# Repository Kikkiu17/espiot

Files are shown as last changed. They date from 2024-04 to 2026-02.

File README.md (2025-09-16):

# espiot
A small board built to measure current and voltage of an appliance.<br />
This board was used as a testbed for STM32 ADC oversampler, UART and DMA.<br />
To measure current and voltage values, a 12-bit ADC was used, with an oversampling ratio of 256x and an 8-bit shift to obtain efficient data averaging - this provides stable readings, along with a sampling time of 3.5 cycles for current and 79.5 cycles for voltage. DMA was also used to transfer all the ADC readings into memory without performance losses.

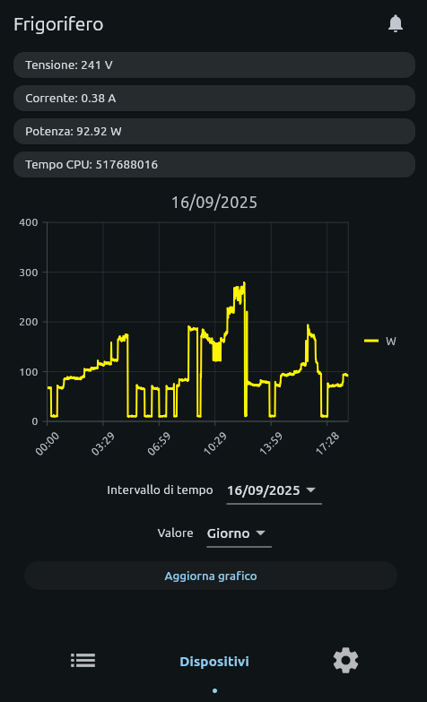
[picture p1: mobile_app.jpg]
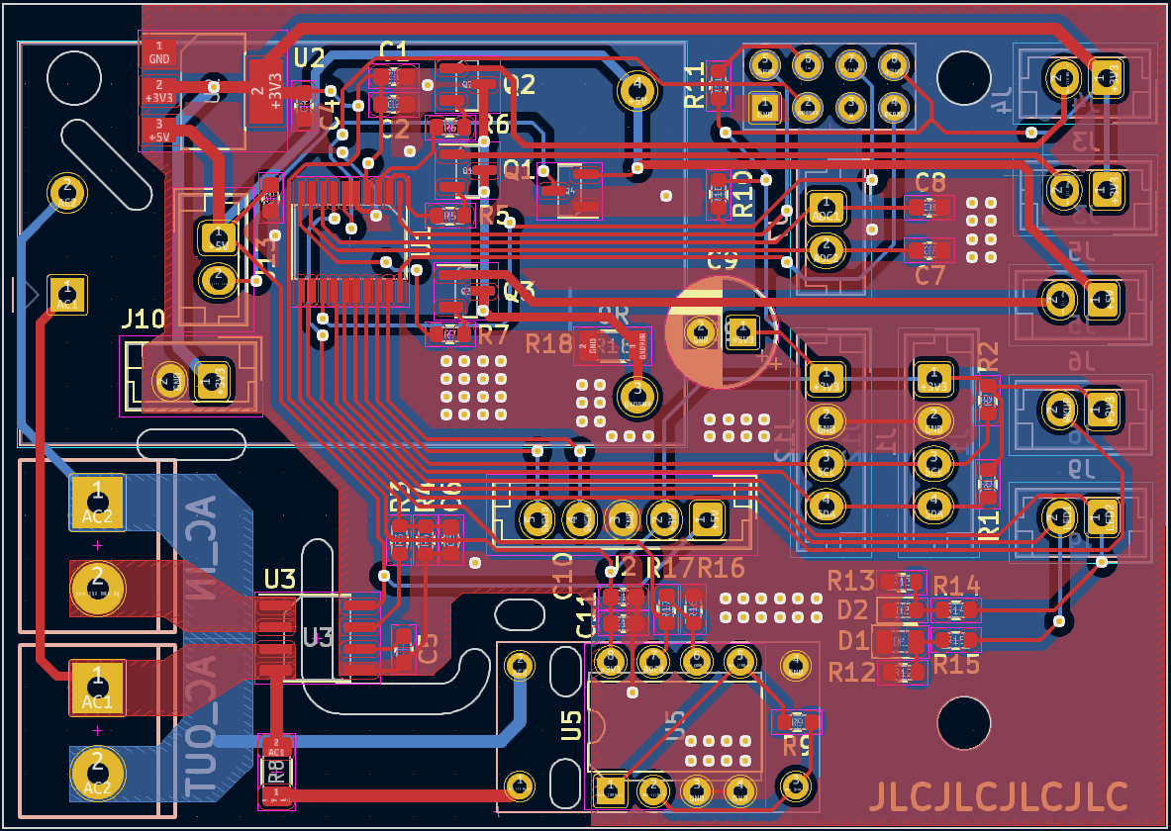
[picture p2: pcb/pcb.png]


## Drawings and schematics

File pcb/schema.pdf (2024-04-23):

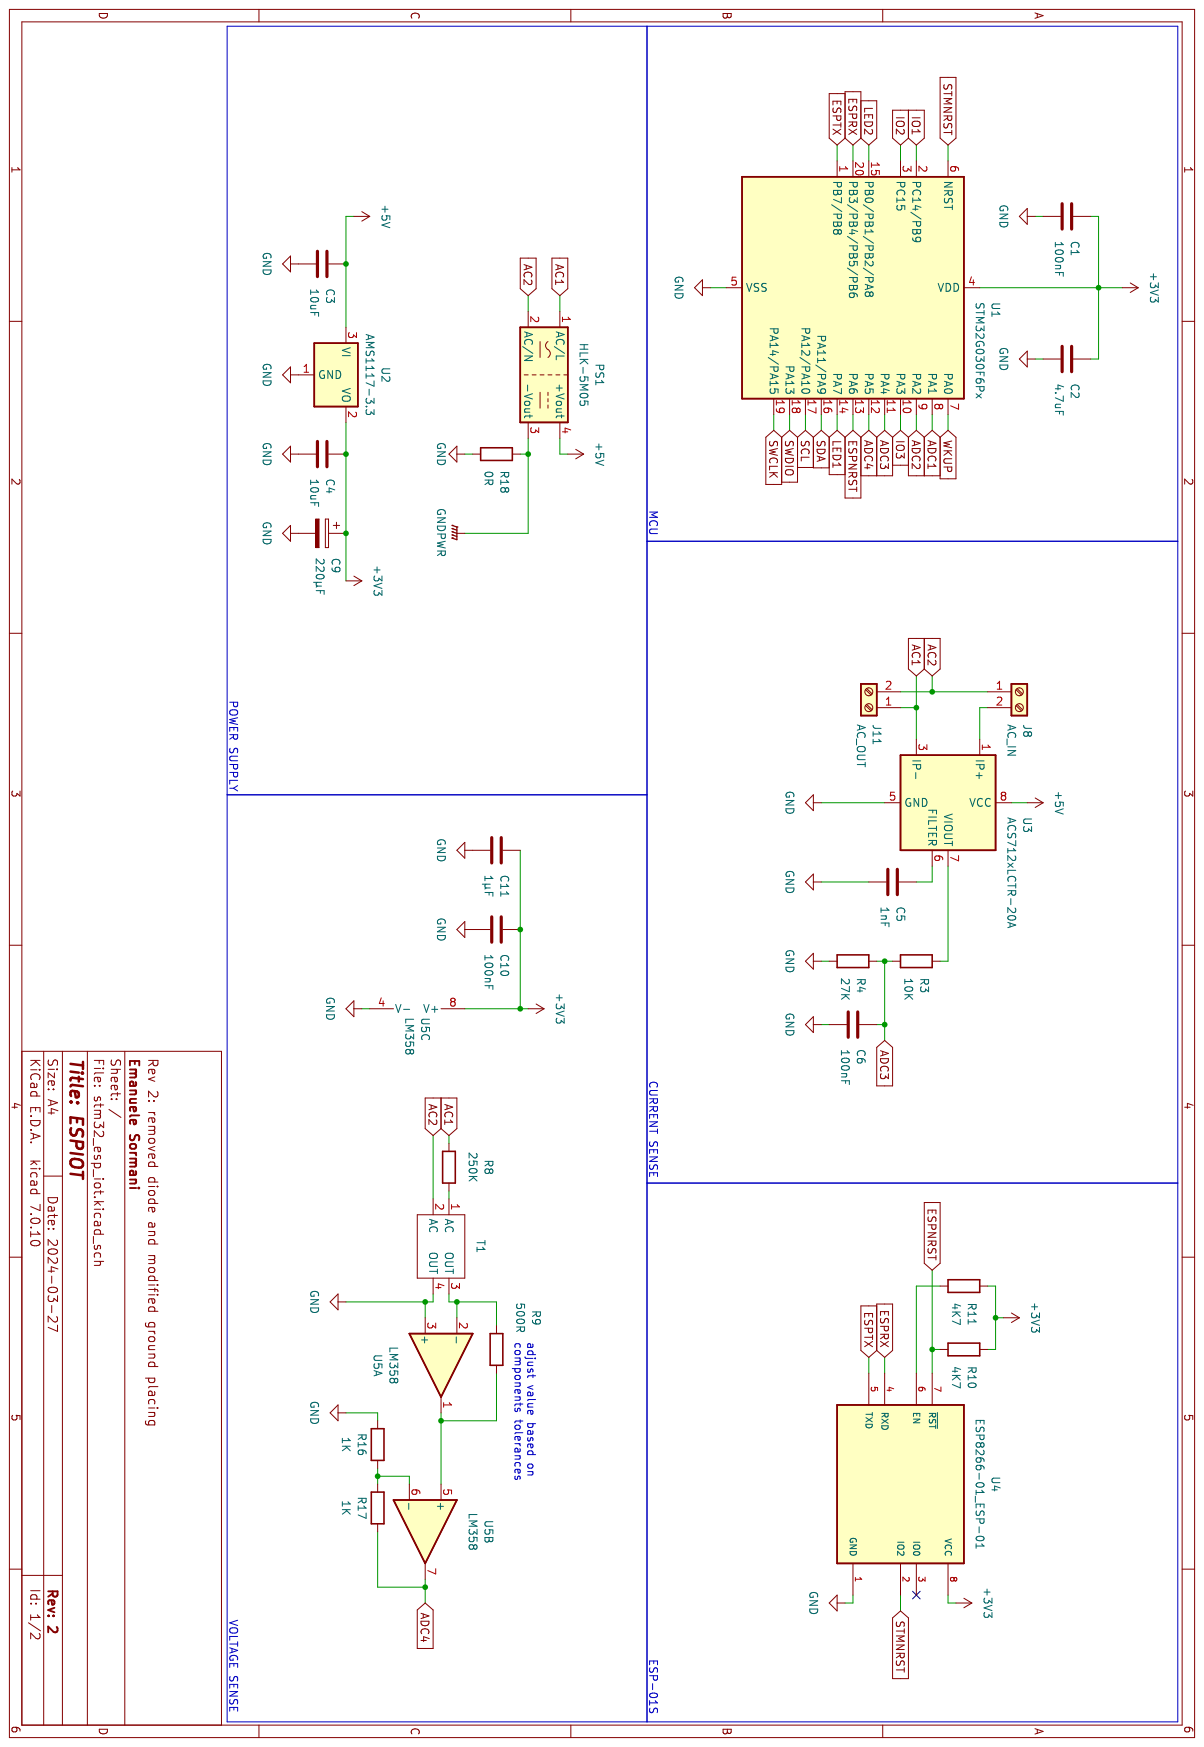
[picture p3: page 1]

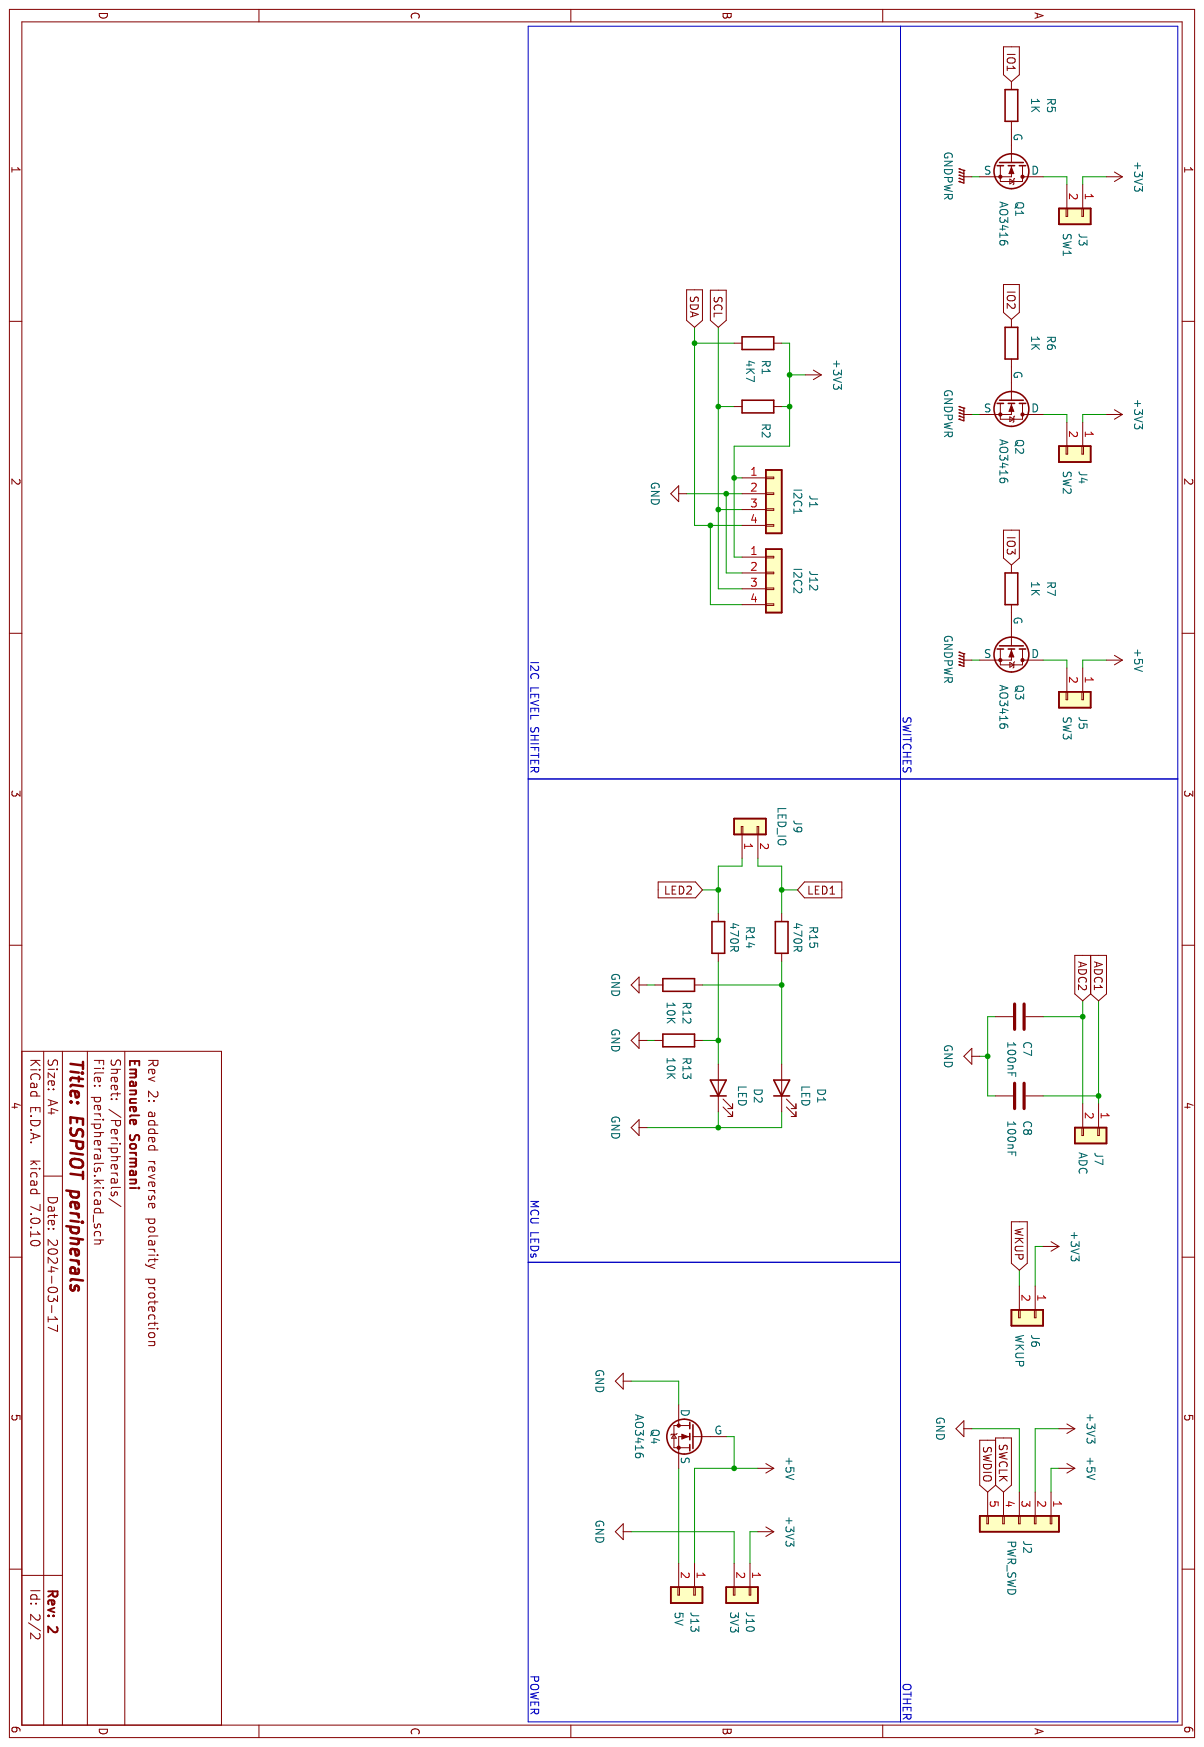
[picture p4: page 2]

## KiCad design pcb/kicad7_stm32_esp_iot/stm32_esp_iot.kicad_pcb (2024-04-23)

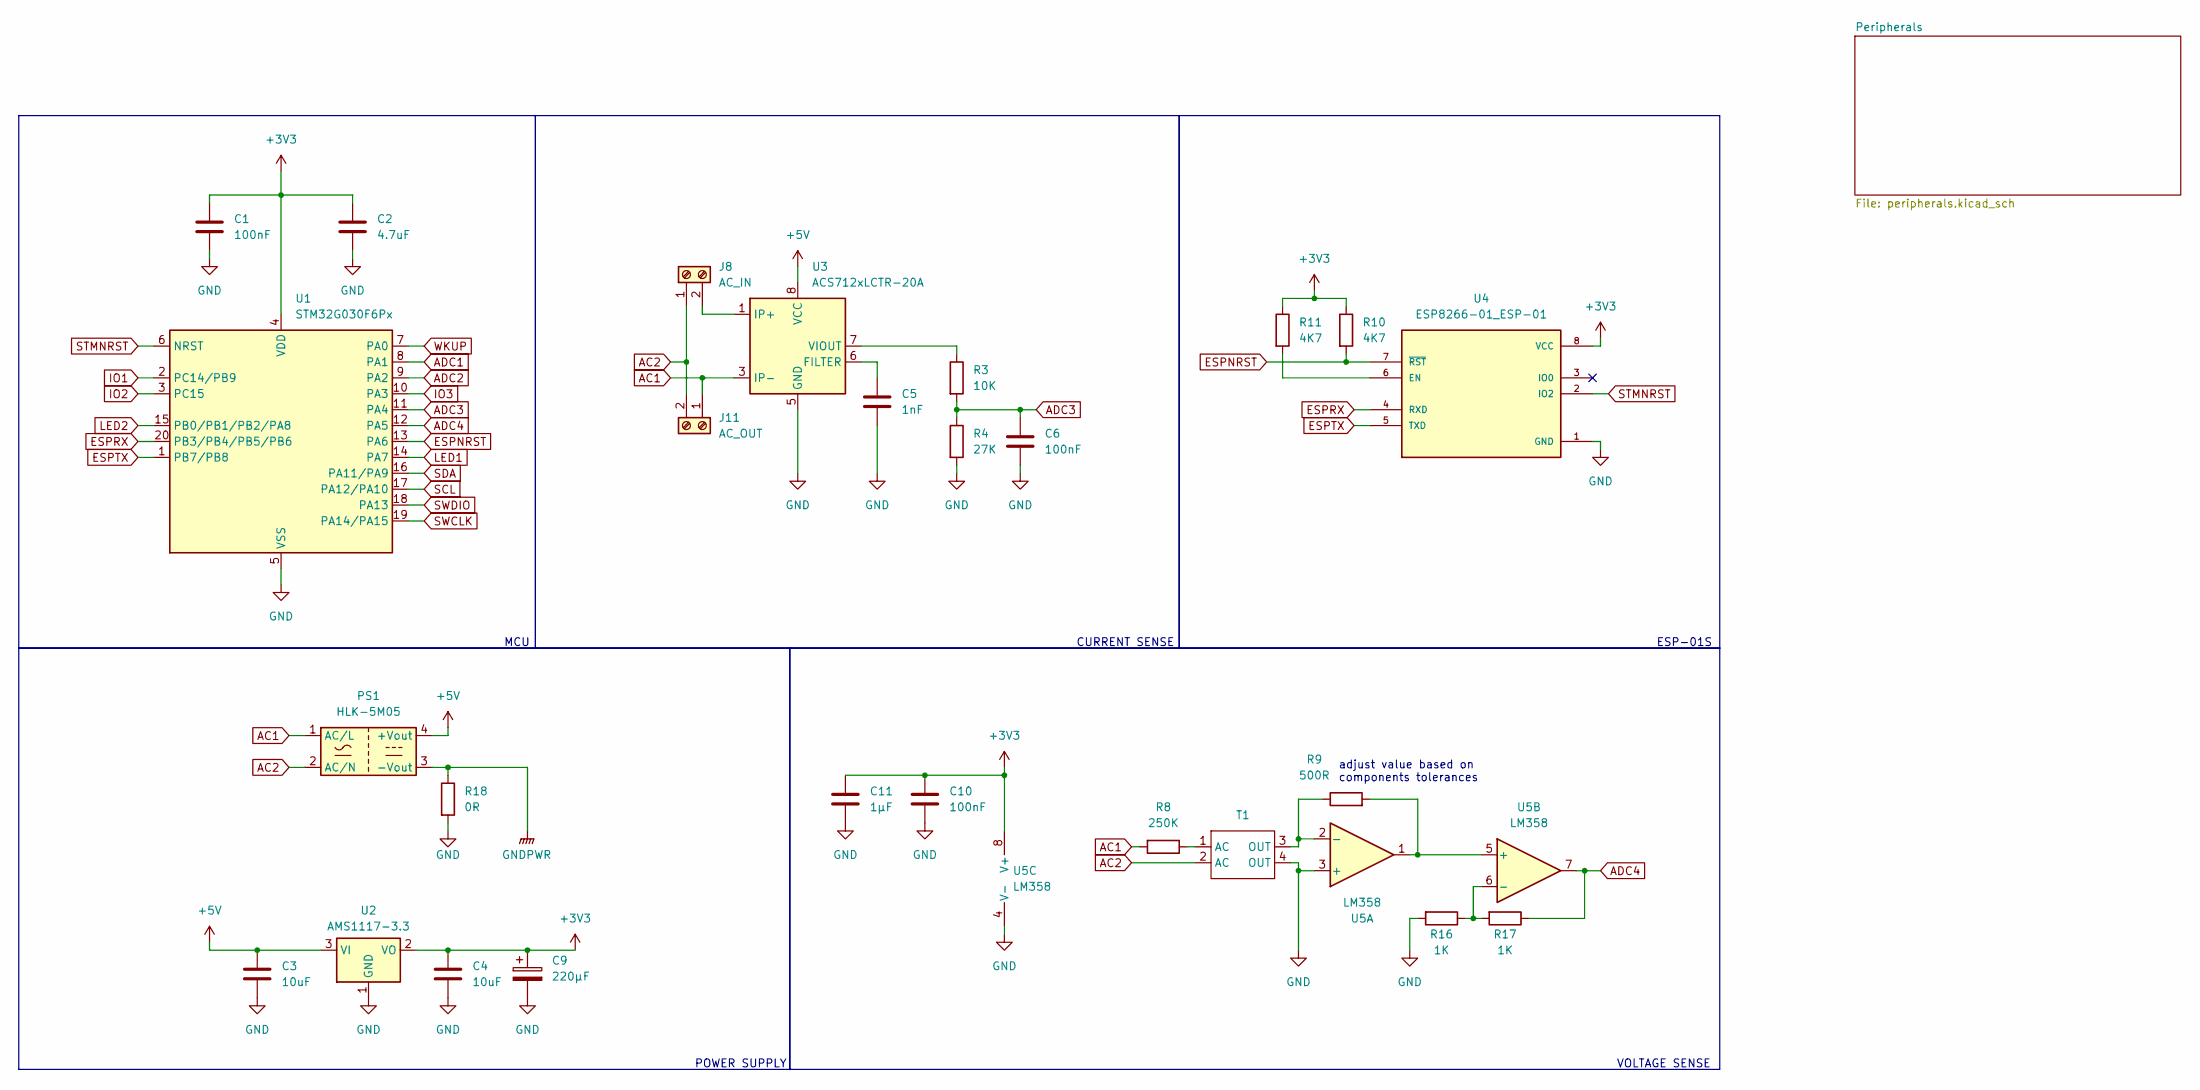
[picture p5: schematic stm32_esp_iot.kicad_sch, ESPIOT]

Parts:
C1, C6, C10: 100nF; C_0603_1608Metric
C2: 4.7uF; C_0603_1608Metric
C3, C4: 10uF; C_0603_1608Metric
C5: 1nF; C_0603_1608Metric
C9: 220µF; CP_Radial_D6.3mm_P2.50mm
C11: 1µF; C_0603_1608Metric
J8: AC_IN; mors_2p
J11: AC_OUT; mors_2p
PS1: HLK-5M05; Converter_ACDC_HiLink_HLK-5Mxx
R3: 10K; R_0603_1608Metric
R4: 27K; R_0603_1608Metric
R8: 250K; R_1206_3216Metric
R9: 500R; R_0603_1608Metric
R10, R11: 4K7; R_0603_1608Metric
R16, R17: 1K; R_0603_1608Metric
R18: 0R; R_1206_3216Metric
T1: ZMPT107
U1: STM32G030F6Px; TSSOP-20_4.4x6.5mm_P0.65mm
U2: AMS1117-3.3; SOT-223-3_TabPin2
U3: ACS712xLCTR-20A; SOIC-8_3.9x4.9mm_P1.27mm
U4: ESP8266-01_ESP-01; esp-01s; PARTREV V1.2
U5: LM358; DIP-8_W7.62mm

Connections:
+3V3: C1.1, C2.1, C4.1, C9.1, C10.1, C11.1, R10.1, R11.1, U1.4 (VDD), U2.2 (VO), U4.8 (VCC), U5.8 (V+); also elsewhere on the board
+5V: C3.1, PS1.4 (+Vout), U2.3 (VI), U3.8 (VCC); also elsewhere on the board
AC1: J11.1, PS1.1 (AC/L), R8.2, U3.3 (IP-), U3.4 (IP-)
AC2: J8.1, J11.2, PS1.2 (AC/N), T1.2 (AC)
ADC1: U1.8 (PA1); also elsewhere on the board
ADC2: U1.9 (PA2); also elsewhere on the board
ADC3: C6.1, R3.2, R4.1, U1.11 (PA4)
ADC4: R17.1, U1.12 (PA5), U5.7
ESPNRST: R10.2, U1.13 (PA6), U4.7 (~RST)
ESPRX: U1.20 (PB3/PB4/PB5/PB6), U4.4 (RXD)
ESPTX: U1.1 (PB7/PB8), U4.5 (TXD)
GND: C1.2, C2.2, C3.2, C4.2, C5.2, C6.2, C9.2, C10.2, C11.2, R4.2, R16.2, R18.2, T1.4 (OUT), U1.5 (VSS), U2.1 (GND), U3.5 (GND), U4.1 (GND), U5.3 (+), U5.4 (V-); also elsewhere on the board
GNDPWR: PS1.3 (-Vout), R18.1; also elsewhere on the board
IO1: U1.2 (PC14/PB9); also elsewhere on the board
IO2: U1.3 (PC15); also elsewhere on the board
IO3: U1.10 (PA3); also elsewhere on the board
LED1: U1.14 (PA7); also elsewhere on the board
LED2: U1.15 (PB0/PB1/PB2/PA8); also elsewhere on the board
unnamed: J8.2, U3.1 (IP+), U3.2 (IP+)
unnamed: R8.1, T1.1 (AC)
unnamed: C5.1, U3.6 (FILTER)
unnamed: R3.1, U3.7 (VIOUT)
unnamed: R11.2, U4.6 (EN)
unnamed: R9.1, T1.3 (OUT), U5.2 (-)
unnamed: R9.2, U5.1, U5.5 (+)
unnamed: R16.1, R17.2, U5.6 (-)
SCL: U1.17 (PA12/PA10); also elsewhere on the board
SDA: U1.16 (PA11/PA9); also elsewhere on the board
STMNRST: U1.6 (NRST), U4.2 (IO2)
SWCLK: U1.19 (PA14/PA15); also elsewhere on the board
SWDIO: U1.18 (PA13); also elsewhere on the board
WKUP: U1.7 (PA0); also elsewhere on the board

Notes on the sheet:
adjust value based on components tolerances
MCU
VOLTAGE SENSE
CURRENT SENSE
ESP-01S
POWER SUPPLY

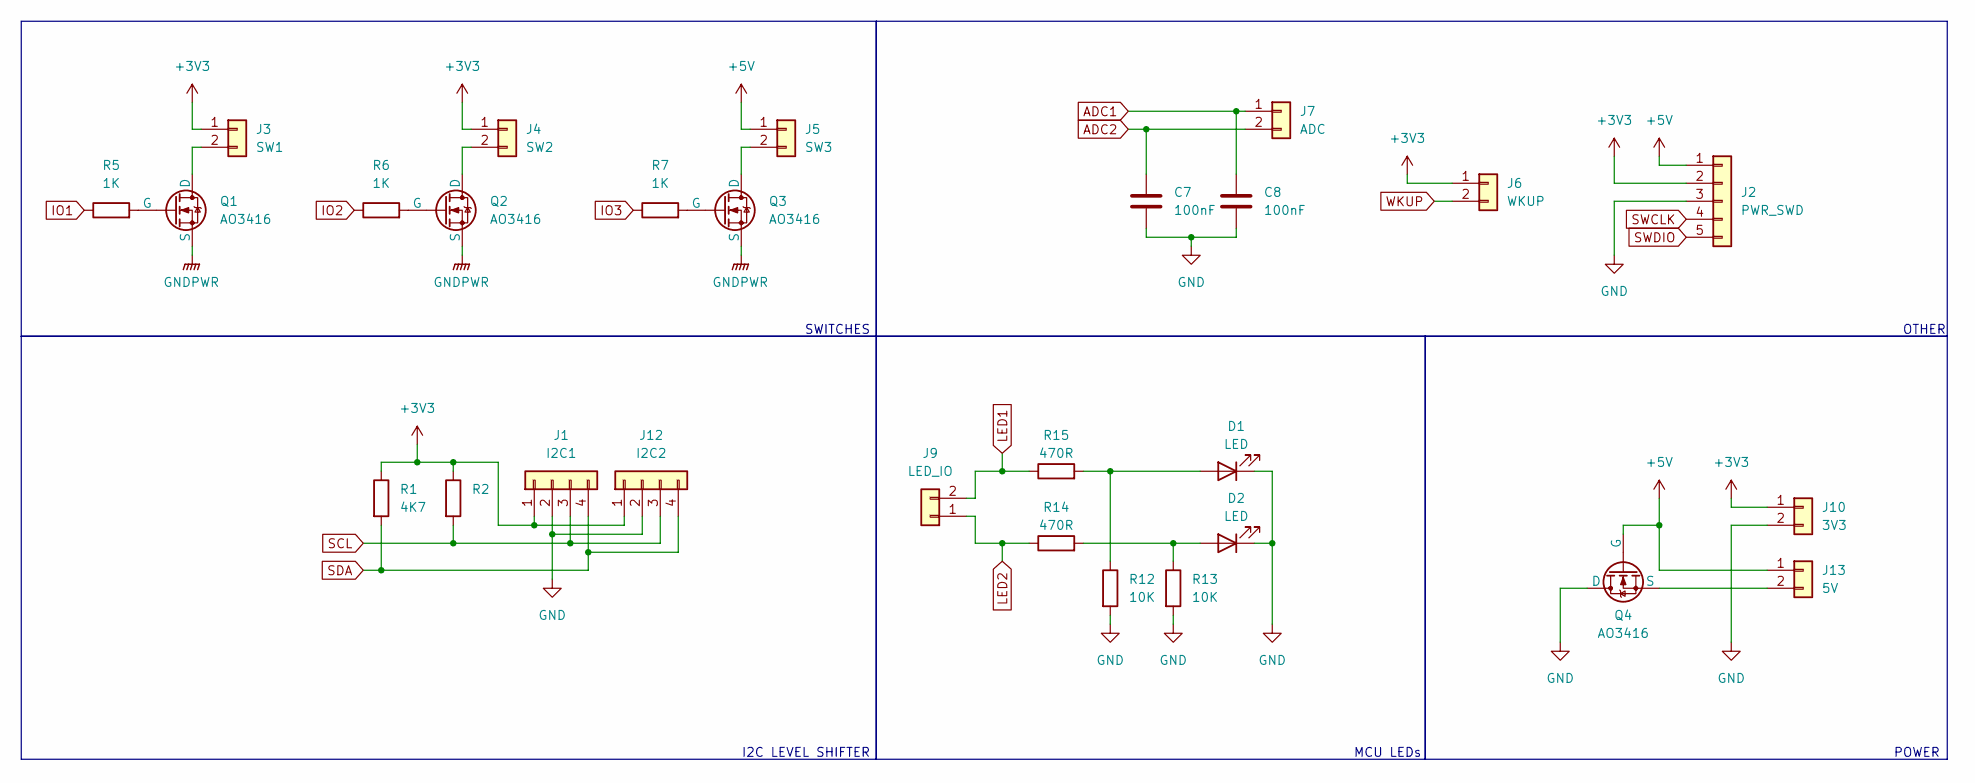
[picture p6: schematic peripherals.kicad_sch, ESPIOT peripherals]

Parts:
C7, C8: 100nF; C_0603_1608Metric
D1: LED; LED_0805_2012Metric
D2: LED; LED_0603_1608Metric
J1: I2C1; JST_EH_B4B-EH-A_1x04_P2.50mm_Vertical
J2: PWR_SWD; JST_EH_B5B-EH-A_1x05_P2.50mm_Vertical
J3: SW1; JST_EH_B2B-EH-A_1x02_P2.50mm_Vertical
J4: SW2; JST_EH_B2B-EH-A_1x02_P2.50mm_Vertical
J5: SW3; JST_EH_B2B-EH-A_1x02_P2.50mm_Vertical
J6: WKUP; JST_EH_B2B-EH-A_1x02_P2.50mm_Vertical
J7: ADC; JST_EH_B2B-EH-A_1x02_P2.50mm_Vertical
J9: LED_IO; JST_EH_B2B-EH-A_1x02_P2.50mm_Vertical
J10: 3V3; JST_EH_B2B-EH-A_1x02_P2.50mm_Vertical
J12: I2C2; JST_EH_B4B-EH-A_1x04_P2.50mm_Vertical
J13: 5V; JST_EH_B2B-EH-A_1x02_P2.50mm_Vertical
Q1, Q2, Q3, Q4: AO3416; SOT-23
R1, R2: 4K7; R_0603_1608Metric
R5, R6, R7: 1K; R_0603_1608Metric
R12, R13: 10K; R_0603_1608Metric
R14, R15: 470R; R_0603_1608Metric

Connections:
+3V3: J1.1, J2.2, J3.1, J4.1, J6.1, J10.1, J12.1, R1.1, R2.1; also elsewhere on the board
+5V: J2.1, J5.1, J13.1, Q4.2 (G); also elsewhere on the board
ADC1: C8.1, J7.1; also elsewhere on the board
ADC2: C7.1, J7.2; also elsewhere on the board
GND: C7.2, C8.2, D1.1 (K), D2.1 (K), J1.2, J2.3, J10.2, J12.2, Q4.1 (D), R12.2, R13.2; also elsewhere on the board
GNDPWR: Q1.3 (S), Q2.3 (S), Q3.3 (S); also elsewhere on the board
IO1: R5.1; also elsewhere on the board
IO2: R6.1; also elsewhere on the board
IO3: R7.1; also elsewhere on the board
LED1: J9.2, R15.1; also elsewhere on the board
LED2: J9.1, R14.1; also elsewhere on the board
unnamed: D1.2 (A), R12.1, R15.2
unnamed: D2.2 (A), R13.1, R14.2
unnamed: J3.2, Q1.1 (D)
unnamed: J4.2, Q2.1 (D)
unnamed: J5.2, Q3.1 (D)
unnamed: J13.2, Q4.3 (S)
unnamed: Q1.2 (G), R5.2
unnamed: Q2.2 (G), R6.2
unnamed: Q3.2 (G), R7.2
SCL: J1.3, J12.3, R2.2; also elsewhere on the board
SDA: J1.4, J12.4, R1.2; also elsewhere on the board
SWCLK: J2.4; also elsewhere on the board
SWDIO: J2.5; also elsewhere on the board
WKUP: J6.2; also elsewhere on the board

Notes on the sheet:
POWER
SWITCHES
MCU LEDs
I2C LEVEL SHIFTER
OTHER

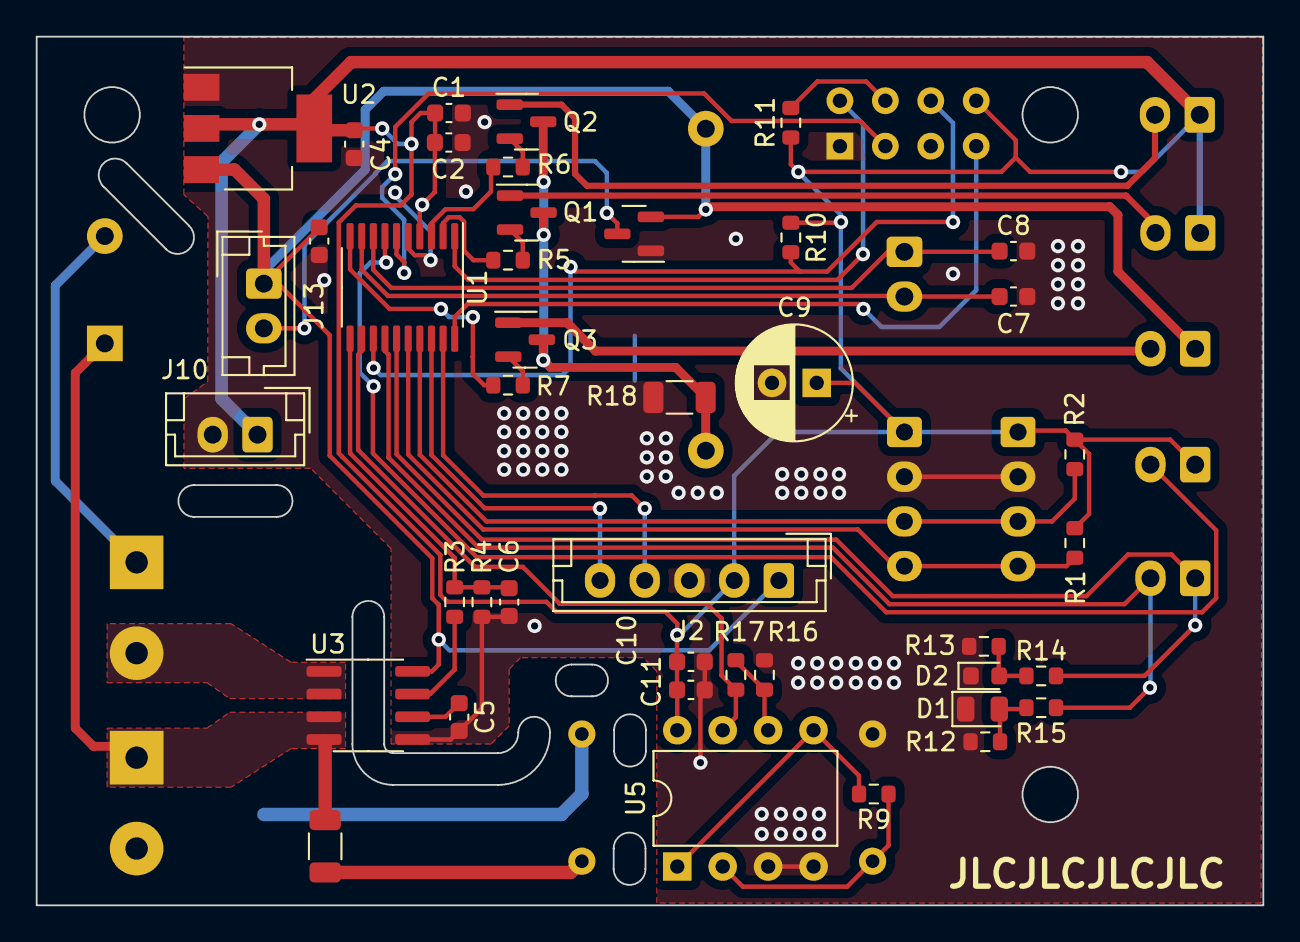
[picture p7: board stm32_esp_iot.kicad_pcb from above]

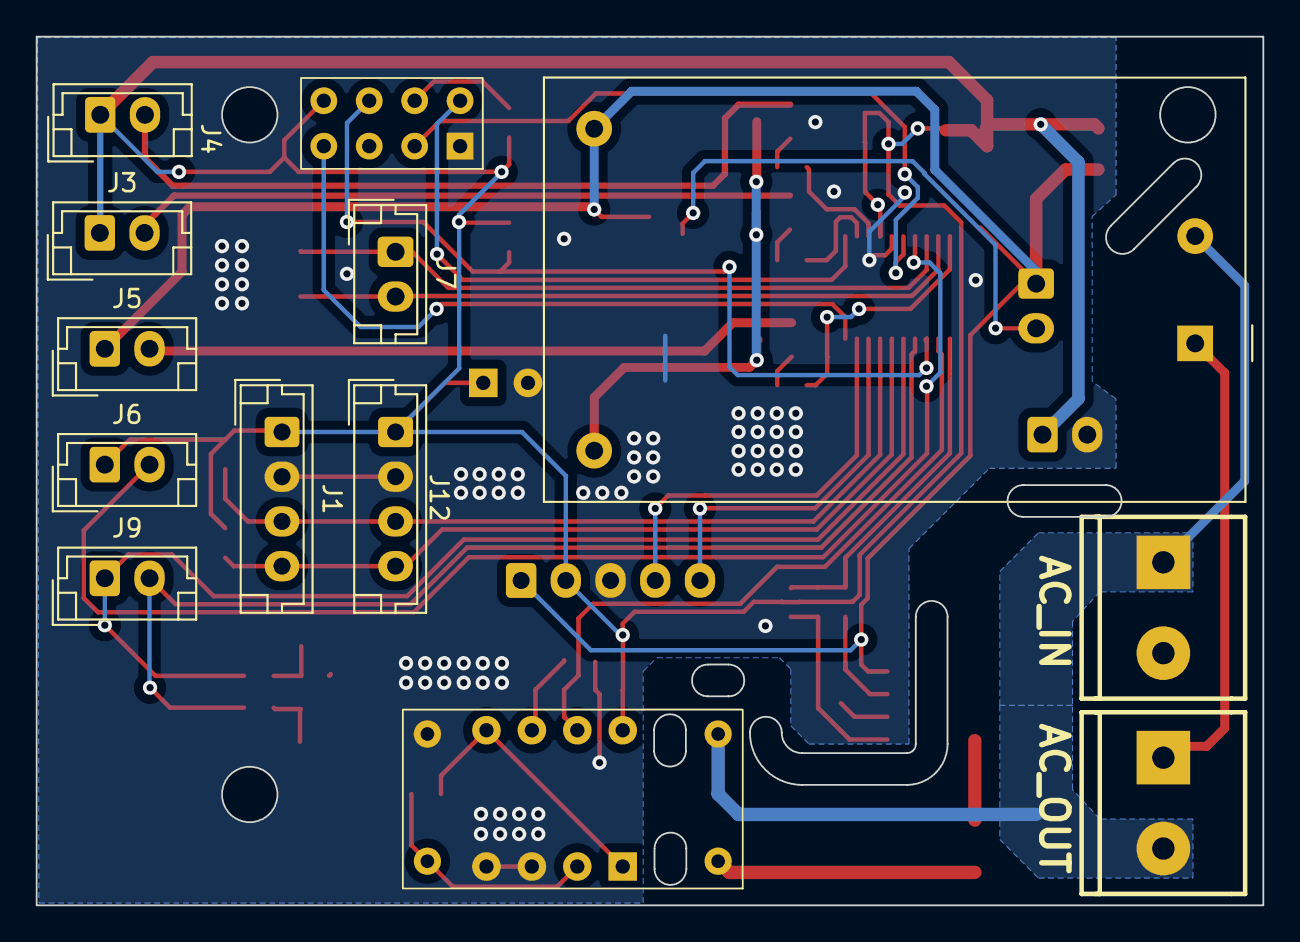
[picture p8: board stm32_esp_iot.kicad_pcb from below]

Board: 2 copper layers, 68.6 x 48.6 mm, 55 parts (13 on the bottom side), 41 nets.

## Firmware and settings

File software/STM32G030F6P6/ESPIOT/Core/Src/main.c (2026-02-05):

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
/* Includes ------------------------------------------------------------------*/
#include "main.h"
#include "adc.h"
#include "dma.h"
#include "tim.h"
#include "usart.h"
#include "gpio.h"

/* USER CODE BEGIN Includes */
#include <string.h>
#include <math.h>
#include <stdio.h>

#include "../credentials.h"
#include "../ESP8266/esp8266.h"
#include "../wifihandler/wifihandler.h"
#include "../Flash/flash.h"
/* USER CODE END Includes */


/* USER CODE BEGIN PV */
uint16_t adc_buf[ADC_BUF_LEN];
uint32_t previous_voltage = 0;

WIFI_t wifi;
Connection_t conn;
/* USER CODE END PV */

void SystemClock_Config(void);
/* USER CODE BEGIN 0 */
float SENS_GetCurrent()
{
	float max = 0, min = 4096;
	// 12-bit ADC must be used
	for (uint32_t i = 0; i < ADC_BUF_LEN; i+=2)
	{
		if (adc_buf[i] > max)
			max = adc_buf[i];
		if (adc_buf[i] < min)
			min = adc_buf[i];
	}

	max = max / 4096.0 * 3.3;
	min = min / 4096.0 * 3.3;

	/*
	 * Irms = measured_amplitude * divider_ratio / 2 / ACS712_sensitivity / √2
	 * where
	 * masured_amplitude = fabsf(max - min)
	 * divider_ratio = 1.37 (voltage divider ratio)
	 * division by two is used to get only one side of the sine wave
	 * ACS712_sensitivity = 0.185 mV/A
	 * division by √2 is used to get RMS value
	 *
	 * the numbers below are obtained by doing these multiplications and division in advance
	 */

	// adjust_value == 1.37 * 1.9145
	float adjust_value = 2.62286;
	float abs_amplitude = fabsf(max - min);
	// used with this particular ACS sensor, since its reading is not linear under 0.6A
	if (abs_amplitude < 0.25)
		adjust_value = 2.09;

	// abs_amplitude * 1.37 * 1.9145
	float Irms = abs_amplitude * adjust_value * CURRENT_CALIB_VALUE;

	if (Irms <= CURRENT_DEAD_ZONE) return 0;
	else return Irms;
}


uint32_t SENS_GetVoltage()
{
	// 12-bit ADC must be used
	uint32_t voltage_mean = 0, voltage = 0;
	for (uint32_t i = 1; i < ADC_BUF_LEN; i+=2)
		voltage_mean += adc_buf[i];

	/*
	 * 0.001745 = 3.3 / (4096 * 1024) * 2255
	 * 2255 is a calibration value. the voltage output of the operational amplifier
	 * has to be multiplied by this value to get the value of the mains voltage
	 * 256x, 8-BIT SHIFT OVERSAMPLER IS REQUIRED!
	 */

	voltage = (float)voltage_mean * 0.001731;
	if (voltage > 250)
		return 230;

	voltage = (voltage + previous_voltage) / 2;
		previous_voltage = voltage;

	return voltage * VOLTAGE_CALIB_VALUE;
}


HAL_StatusTypeDef ESP_SendRawValue(uint32_t value, uint32_t received_byte)
{
	uint8_t send_buffer[11];
	uint32_t raw_value = *(uint32_t*)&value;

	for (int32_t i = 10; i >= 1; i--)
	{
		send_buffer[i] = raw_value % 10;
		raw_value /= 10;
	}
	send_buffer[0] = received_byte;

	GPIOA->BSRR |= GPIO_PIN_7;
	HAL_StatusTypeDef status = HAL_UART_Transmit(&huart1, send_buffer, 11, HAL_MAX_DELAY);
	GPIOA->BRR |= GPIO_PIN_7;
	return status;
}
/* USER CODE END 0 */

/**
  * @brief  The application entry point.
  * @retval int
  */
int main(void)
{

  /* MCU Configuration--------------------------------------------------------*/

  /* Reset of all peripherals, Initializes the Flash interface and the Systick. */
  HAL_Init();

  /* Configure the system clock */
  SystemClock_Config();

  /* Initialize all configured peripherals */
  MX_GPIO_Init();
  MX_DMA_Init();
  MX_ADC1_Init();
  MX_USART1_UART_Init();
  MX_TIM3_Init();
  /* USER CODE BEGIN 2 */
  if (ESP8266_Init() == TIMEOUT)
  {
	  while (1)
		  __NOP();
  }

#ifdef ENABLE_SAVE_TO_FLASH
  FLASH_ReadSaveData();
  if (WIFI_SetName(&wifi, savedata.name) == ERR)
    WIFI_SetName(&wifi, (char*)ESP_NAME); // happens when there is nothing saved to FLASH, so set default name
  WIFI_SetIP(&wifi, savedata.ip);         // if there is nothing saved to FLASH, this function does nothing
#else
  WIFI_SetName(&wifi, (char*)ESP_NAME);
#endif

  memcpy(wifi.SSID, ssid, strlen(ssid));
  memcpy(wifi.pw, password, strlen(password));
  HAL_GPIO_WritePin(STATUS_Port, STATUS_Pin, 1);
  uint32_t connect_status = WIFI_Connect(&wifi);
  if (connect_status == FAIL || connect_status == ERROR)
  {
    // try again
    NVIC_SystemReset();
  }
  HAL_GPIO_WritePin(STATUS_Port, STATUS_Pin, 0);
  WIFI_EnableNTPServer(&wifi, 0);

  /*
  The first time the ESP connects to WiFi, the gateway assigns an IP to it, which now gets saved to FLASH.
  The next time the ESP connects, the gateway could assign a different IP; to prevent this, the function
  WIFI_SetIP(&wifi, savedata.ip); loads the IP previously saved on FLASH so that the ESP tries to connect
  and get this IP
  */
  strncpy(savedata.ip, wifi.IP, 15);
  FLASH_WriteSaveData();

  WIFI_StartServer(&wifi, SERVER_PORT);

  HAL_ADCEx_Calibration_Start(&hadc1);
  HAL_ADC_Start_DMA(&hadc1, (uint32_t*)&adc_buf, ADC_BUF_LEN);
  HAL_TIM_Base_Start(&htim3);
  /* USER CODE END 2 */

  /* Infinite loop */
  /* USER CODE BEGIN WHILE */
  Response_t wifistatus = WAITING;
  HAL_GPIO_WritePin(GPIOB, GPIO_PIN_0, 1);
  //uint32_t reconnection_timestamp = 0;
  while (1)
  {
	  /*if (uwTick - reconnection_timestamp > RECONNECTION_DELAY_MILLIS)
	  {
		  // check every RECONNECTION_DELAY_MINS if this device is connected to wifi. if it is, get
		  // latest connection info, otherwise connect
		  WIFI_Connect(&wifi);
		  reconnection_timestamp = uwTick;
	  }*/

	  wifistatus = WAITING;
	  // HANDLE WIFI CONNECTION
	  wifistatus = WIFI_ReceiveRequest(&wifi, &conn, AT_SHORT_TIMEOUT);
	  if (wifistatus == OK)
	  {
		  HAL_GPIO_TogglePin(STATUS_Port, STATUS_Pin);
		  char* key_ptr = NULL;

		  if ((key_ptr = WIFI_RequestHasKey(&conn, "wifi")))
			  WIFIHANDLER_HandleWiFiRequest(&conn, key_ptr);

		  else if (conn.request_type == GET)
		  {
			  if ((key_ptr = WIFI_RequestHasKey(&conn, "features")))
			  {
				  feature_voltage = SENS_GetVoltage();
				  float current = SENS_GetCurrent();
				  if (current < CURRENT_THRESHOLD)
					  current = 0.0f;
				  feature_current_integer_part = current;
				  feature_current_decimal_part = current * 100 - feature_current_integer_part * 100;
				  float power = feature_voltage * current;
				  feature_power_integer_part = power;
				  feature_power_decimal_part = power * 100 - feature_power_integer_part * 100;
				  WIFIHANDLER_HandleFeaturePacket(&conn, (char*)FEATURES_TEMPLATE);
			  }
			  else if ((key_ptr = WIFI_RequestHasKey(&conn, "notification")))
				  WIFIHANDLER_HandleNotificationRequest(&conn, key_ptr);
			  // other GET requests code here...

			  else WIFI_SendResponse(&conn, "404 Not Found", "Unknown command", 15);
		  }

		  else if (conn.request_type == POST)
		  {
			  // other POST requests code here...
		  }

		  // other requests code here...

		  HAL_GPIO_TogglePin(STATUS_Port, STATUS_Pin);
	  }
	  else if (wifistatus != TIMEOUT)
	  {
		  sprintf(wifi.buf, "Status: %d", wifistatus);
		  WIFI_ResetComm(&wifi, &conn);
		  WIFI_SendResponse(&conn, "500 Internal server error", wifi.buf, strlen(wifi.buf));
	  }

	  WIFI_ResetConnectionIfError(&wifi, &conn, wifistatus);
	  /*uint8_t uart_buf[11];
	  GPIOB->BSRR |= GPIO_PIN_0;
	  HAL_UART_Receive(&huart1, uart_buf, 11, 10);
	  GPIOB->BRR |= GPIO_PIN_0;
	  //HAL_Delay(250);
	  if (uart_buf[0] == 0x10)
	  {
		  uart_buf[0] = 0x00;
		  uint8_t data[1] = {0x01};
		  HAL_UART_Transmit(&huart1, data, 1, HAL_MAX_DELAY);
	  }
	  else if (uart_buf[0] == 0x12)
	  {
		  uart_buf[0] = 0x00;
		  float current = SENS_GetCurrent();
		  ESP_SendRawValue(*(uint32_t*)&current, 0x12);
	  }
	  else if (uart_buf[0] == 0x13)
	  {
		  uart_buf[0] = 0x00;
		  uint32_t voltage = SENS_GetVoltage();
		  ESP_SendRawValue(voltage, 0x13);
	  }
	  else if (uart_buf[0] == 0x14)
	  {
		  uart_buf[0] = 0x00;
		  // the power value can be calculated in the esp8266, but why not doing it here?
		  uint32_t power = SENS_GetVoltage() * SENS_GetCurrent();
		  ESP_SendRawValue(power, 0x14);
	  }
	  else if (uart_buf[0] == 0x15)
	  {
		  NVIC_SystemReset();
	  }*/
    /* USER CODE END WHILE */

    /* USER CODE BEGIN 3 */
  }
  /* USER CODE END 3 */
}

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
/* USER CODE BEGIN 4 */
/*void HAL_UART_RxCpltCallback(UART_HandleTypeDef *huart)
{
    //HAL_UART_Transmit(&huart1, UART1_rxBuffer, 12, 100);
    HAL_UART_Receive_DMA(&huart1, usart_buf, 16);
}*/

/*void HAL_ADC_ConvCpltCallback(ADC_HandleTypeDef *hadc)
{
}*/

/*void HAL_ADC_ConvHalfCpltCallback(ADC_HandleTypeDef *hadc)
{
	uint32_t maxx = 0, minn = 4096;
	// 12-bit ADC must be used
	for (uint32_t i = 0; i < ADC_BUF_LEN; i+=2)
	{
		if (adc_buf[i] > maxx)
			maxx = adc_buf[i];
		if (adc_buf[i] < minn)
			minn = adc_buf[i];
	}

	max = (float)maxx;
	min = (float)minn;
}*/

/* USER CODE END 4 */
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


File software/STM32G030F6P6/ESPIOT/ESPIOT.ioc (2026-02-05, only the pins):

Mcu.UserName=STM32G030F6Px
PA13.Signal=SYS_SWDIO
PA14-BOOT0.Signal=SYS_SWCLK
PA4.Signal=ADC1_IN4
PA5.Signal=ADC1_IN5
PA6.GPIO_Label=ESPRST
PA6.Signal=GPIO_Output
PA7.Signal=GPIO_Output
PB0.Signal=GPIO_Output
PB6.Signal=USART1_TX
PB7.Signal=USART1_RX

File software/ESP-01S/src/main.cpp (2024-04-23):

#include <ESP8266WiFi.h>
#include <ESPAsyncTCP.h>

#include <ESPAsyncWebServer.h>
#include <ElegantOTA.h>
#include <WebSerial.h>
#include <BlockNot.h>

#include "com.h"
// CALIBRATE DEVICE HERE
#include "calibrationvalues.h"

const char* ssid = "xxxxxxxxxxxxxx";
const char* password = "xxxxxxxxxxxxxxxxxxx";

// switch;sensor:power,current
// sensor:power,voltage,current
const String capabilities = "sensor:power,voltage,current";
//const String capabilities = "sensor:power,current";
const String id = "ESPDEVICE002";

AsyncWebServer server(80);

unsigned long ota_progress_millis = 0;

void onOTAEnd(bool success)
{
  // Log when OTA has finished
  if (success) {
  }
  // <Add your own code here>
}

void onOTAStart() {
  // Log when OTA has started
  Serial.println("OTA update started!");
  // <Add your own code here>
}

void onOTAProgress(size_t current, size_t final) {
  // Log every 1 second
  if (millis() - ota_progress_millis > 1000) {
    ota_progress_millis = millis();
    Serial.printf("OTA Progress Current: %u bytes, Final: %u bytes\n", current, final);
  }
}

uint32_t bufferToNumber(uint8_t *buf, size_t size)
{
  uint32_t number = 0;
  for (uint32_t i = 1; i < size; i++)
    number = number * 10 + buf[i];
  return number;
}

float current = 0.00;
uint32_t voltage = 0;
uint32_t power = 0.00;
char send_buf[4];
String own_name = "NAME_NOT_SET";

// ADD HERE CAPABILITIES RETURN
void handleSensorParams(AsyncWebServerRequest *req)
{
  String response;
  bool found = false;
  for (uint32_t i = 0; i < req->params(); i++)
  {
    AsyncWebParameter *p = req->getParam(i);

    if (p->name() == "current" && p->value() == "1")
    {
      found = true;
      if (response != "")
        response += ";";
      response += "current:" + String(current);
      continue;
    }

    if (p->name() == "voltage" && p->value() == "1")
    {
      found = true;
      if (response != "")
        response += ";";
      response += "voltage:" + String(voltage);
      continue;
    }

    if (p->name() == "power" && p->value() == "1")
    {
      found = true;
      if (response != "")
        response += ";";
      response += "power:" + String(power);
      continue;
    }
  }

  if (!found)
    req->send(404, "text/plain", "Not Found");
  else
    req->send(200, "text/plain", response);

  return;
}

void setup(void)
{
  Serial.begin(115200);
  WiFi.mode(WIFI_STA);
  WiFi.hostname(id);
  WiFi.begin(ssid, password);

  while (WiFi.status() != WL_CONNECTED)
  {
    delay(500);
  }

  server.on("/capabilities", HTTP_GET, [](AsyncWebServerRequest *request)
  {
    request->send(200, "text/plain", capabilities);
  });

  server.on("/sensor", HTTP_GET, [](AsyncWebServerRequest *request)
  {
    handleSensorParams(request);
  });

  server.on("/name", HTTP_POST, [](AsyncWebServerRequest *request)
  {
    if (request->params() == 0)
      request->send(400, "text/plain", "Bad Request");

    AsyncWebParameter *p = request->getParam(0);

    if (p->name() == "set" && p->value() != "")
    {
      own_name = p->value();
      request->send(200, "text/plain", "Name set");
    }
    else
      request->send(400, "text/plain", "Bad Request");
  });

  server.on("/name", HTTP_GET, [](AsyncWebServerRequest *request)
  {
    request->send(200, "text/plain", own_name);
  });

  server.on("/id", HTTP_GET, [](AsyncWebServerRequest *request)
  {
    request->send(200, "text/plain", id);
  });

  server.on("/ip", HTTP_GET, [](AsyncWebServerRequest *request)
  {
    request->send(200, "text/plain", WiFi.localIP().toString());
  });

  ElegantOTA.begin(&server);    // Start ElegantOTA
  ElegantOTA.setAutoReboot(true);
  // ElegantOTA callbacks
  ElegantOTA.onStart(onOTAStart);
  ElegantOTA.onProgress(onOTAProgress);
  ElegantOTA.onEnd(onOTAEnd);

  WebSerial.begin(&server);

  server.begin();
  sendByteNoResponse(STM_RESET);
  Serial.flush();
}

uint8_t buf[11];
bool startup = false;
uint32_t timer = 0;

void loop(void)
{
  ElegantOTA.loop();

  if (millis() - timer > 250)
  {
    memset(buf, 0, 11);
    timer = millis();
    if (!startup)
    {
      if (sendByte(STARTUP, buf) != NORESPONSE)
      {
        if (buf[0] == OK)
        {
          sendByte(READY, buf);
          startup = true;
        }
        else if (buf[0] == FATAL_ERROR)
          while (true) {}
      }
    }

    if (startup)
    {
      if (sendByte(REQUEST_CURRENT, buf) == REQUEST_CURRENT)
      {
        uint32_t raw_number = bufferToNumber(buf, 11);
        current = roundf(*reinterpret_cast<float*>(&raw_number) * 100) / 100 - amps_subtracted;
        if (current < amps_deadzone)
          current = 0;
      }

      if (sendByte(REQUEST_VOLTAGE, buf) == REQUEST_VOLTAGE)
      {
        voltage = bufferToNumber(buf, 11) - volts_subtracted;
      }

      if (sendByte(REQUEST_POWER, buf) == REQUEST_POWER)
      {
        //power = voltage * current;
        power = bufferToNumber(buf, 11);
        // brings the power to zero to account for software calibration
        /*if (power > current * voltage && amps_deadzone != 0)
         power = 0;*/
      }
    }
  }
}

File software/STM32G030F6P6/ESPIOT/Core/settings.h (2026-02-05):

/*
 * features.h
 *
 *  Created on: Aug 6, 2025
 *      Author: kikkiu
 */

#ifndef SETTINGS_H_
#define SETTINGS_H_

typedef uint8_t bool;
#define true 1
#define false 0

// CHANGE THESE SETTINGS ACCORDING TO YOUR SETUP!!!
#define STM_UART huart1
#define UART_DMA_CHANNEL DMA1_Channel2
#define ESP_RST_PORT ESPRST_GPIO_Port
#define ESP_RST_PIN ESPRST_Pin

#define STATUS_Port GPIOA
#define STATUS_Pin GPIO_PIN_7

#define START_ATTEMPTS -1

// ==========================================================================================
// 										USER DEFINES
// ==========================================================================================

// all times are in milliseconds
#define STROBE_DELAY 4000
#define STROBE_DURATION 12
#define CURRENT_THRESHOLD 0.05 // amperes
#define ADC_BUF_LEN 2048
#define CURRENT_DEAD_ZONE 0.025		// 0.095 without OVERSAMPLING; 0.025 for 256x, 8-bit shift
#define CURRENT_CALIB_VALUE 1.030
#define VOLTAGE_CALIB_VALUE	0.957

// ==========================================================================================
// 											FLASH
// ==========================================================================================
/**
 *				!!!THE LAST PAGE OF THE FLASH MEMORY HAS TO BE BLANK!!!
 * 						!!!CHECK PROGRAM SIZE BEFORE UPLOADING!!!
 */
#define ENABLE_SAVE_TO_FLASH

#ifdef ENABLE_SAVE_TO_FLASH
// check your datasheet for the permitted datatype! STM32G030 can write DWORD on FLASH
typedef uint64_t FLASH_DATATYPE;
#define FLASH_DATASIZE sizeof(FLASH_DATATYPE)
#define LAST_PAGE_ADDRESS 0x08000000 + ((FLASH_PAGE_NB - 1) * FLASH_PAGE_SIZE)
//#define LAST_PAGE_ADDRESS 0x08000000 + FLASH_BANK_SIZE - FLASH_PAGE_SIZE
//#define LAST_PAGE_ADDRESS 0x8007800	// check your datasheet!!!
#endif

// ==========================================================================================
// 									NETWORK (esp8266.h)
// ==========================================================================================
static const char ESP_NAME[] = "Frigo";
#define SERVER_PORT 34677

static const char ESP_HOSTNAME[] = "ESPDEVICE001"; // template: ESPDEVICExxx
//static const char ESP_IP[] = "192.168.1.38";

#define AT_SHORT_TIMEOUT 250
#define AT_MEDIUM_TIMEOUT 500
#define AT_LONG_TIMEOUT 1250

// BUFFERS SIZES (in RAM)

/**
 * RESPONSE_MAX_SIZE
 *
 * this buffer will contain the data to be sent FROM THIS device to the connected device
 * this could correspond to sizeof(FEATURES_TEMPLATE), because it's usually the biggest response
 * this device will send. set this according to your needs
 */
#define RESPONSE_MAX_SIZE 512

/**
 * REQUEST_MAX_SIZE
 *
 * if you don't expect big requests from the remote device, this buffer can be small (usually 128 bytes or less)
 */
#define REQUEST_MAX_SIZE 64

/**
 * WIFI_BUF_MAX_SIZE
 *
 * contains short commands to be sent to the ESP, for example to connect it to WiFi, to get the current IP...
 * (check esp8266.c)
 * if you don't use it directly, it can be left at the default value.
 * NOTE: this can contain the network SSID and PASSWORD, so if those strings are larger than this buffer,
 * the network name and/or its password will be truncated, resulting in no WiFi connection!
 */
#define WIFI_BUF_MAX_SIZE 128

/**
 * UART_BUFFER_SIZE
 *
 * if you have to retrieve large amounts of data (i.e. from an API), set this to the minimum size of the response
 * otherwise, it can be smaller.
 * if you don't have these requirements, you can set it to a minimum of
 * REQUEST_MAX_SIZE + some headroom to avoid receiving only partial messages
 * if you encounter weird behaviors at runtime, try increasing this buffer size
 */
#define UART_BUFFER_SIZE 128

#define HOSTNAME_MAX_SIZE 32		// ESPDEVICExxx
#define NAME_MAX_SIZE 32			// human-readable name

#define UART_TX_TIMEOUT 500			// ms
#define UART_RX_IDLE_TIMEOUT 3000	// ms

#define RECONNECTION_DELAY_MINS 1	// minutes
#define RECONNECTION_DELAY_MILLIS RECONNECTION_DELAY_MINS * 60000

typedef struct notif
{
	char* text;
	uint8_t size;
} Notification_t;

extern Notification_t notification;

// ==========================================================================================
// 										SAVE DATA
// ==========================================================================================
/**
 * The save data will be written to the last page of the memory bank
 * 					!!!See FLASH section at the top of the file!!!
 */

#ifdef ENABLE_SAVE_TO_FLASH
typedef struct sdata
{
	char name[NAME_MAX_SIZE];
	char ip[15 + 1];
} SaveData_t;

extern SaveData_t savedata;
#endif

// ==========================================================================================
// 										COMM TEMPLATE
// ==========================================================================================
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

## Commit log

2024-04-23 Project upload
    [peripherals.kicad_sch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]
2025-09-16 Removed BOM
2025-10-03 Fixed write past array length
    [esp8266.c]
2025-10-03 Fixed name reading issue
    [esp8266.c]
2025-11-30 Added calibration values
2025-12-06 Fixed ESP start problem
    [esp8266.c, main.c]

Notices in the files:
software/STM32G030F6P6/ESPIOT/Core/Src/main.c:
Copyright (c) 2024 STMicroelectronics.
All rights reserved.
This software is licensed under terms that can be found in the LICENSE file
